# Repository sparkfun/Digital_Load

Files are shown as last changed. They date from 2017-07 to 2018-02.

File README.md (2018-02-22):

Digital_Load
==========================================

Variable Load

A PSoC-based digital load that allows the user to set a desired current which will be maintained despite changes in voltage supply.
Check on the [SparkFun Enginursday post](https://www.sparkfun.com/news/2434) about the project build or the [SparkFun Variable Load Kit](https://www.sparkfun.com/products/14449) that uses this design. 

License Information
-------------------

This product is _**open source**_! 

Please review the LICENSE.md file for license information. 

If you have any questions or concerns on licensing, please contact techsupport@sparkfun.com.

Distributed as-is; no warranty is given.

- Your friends at SparkFun.

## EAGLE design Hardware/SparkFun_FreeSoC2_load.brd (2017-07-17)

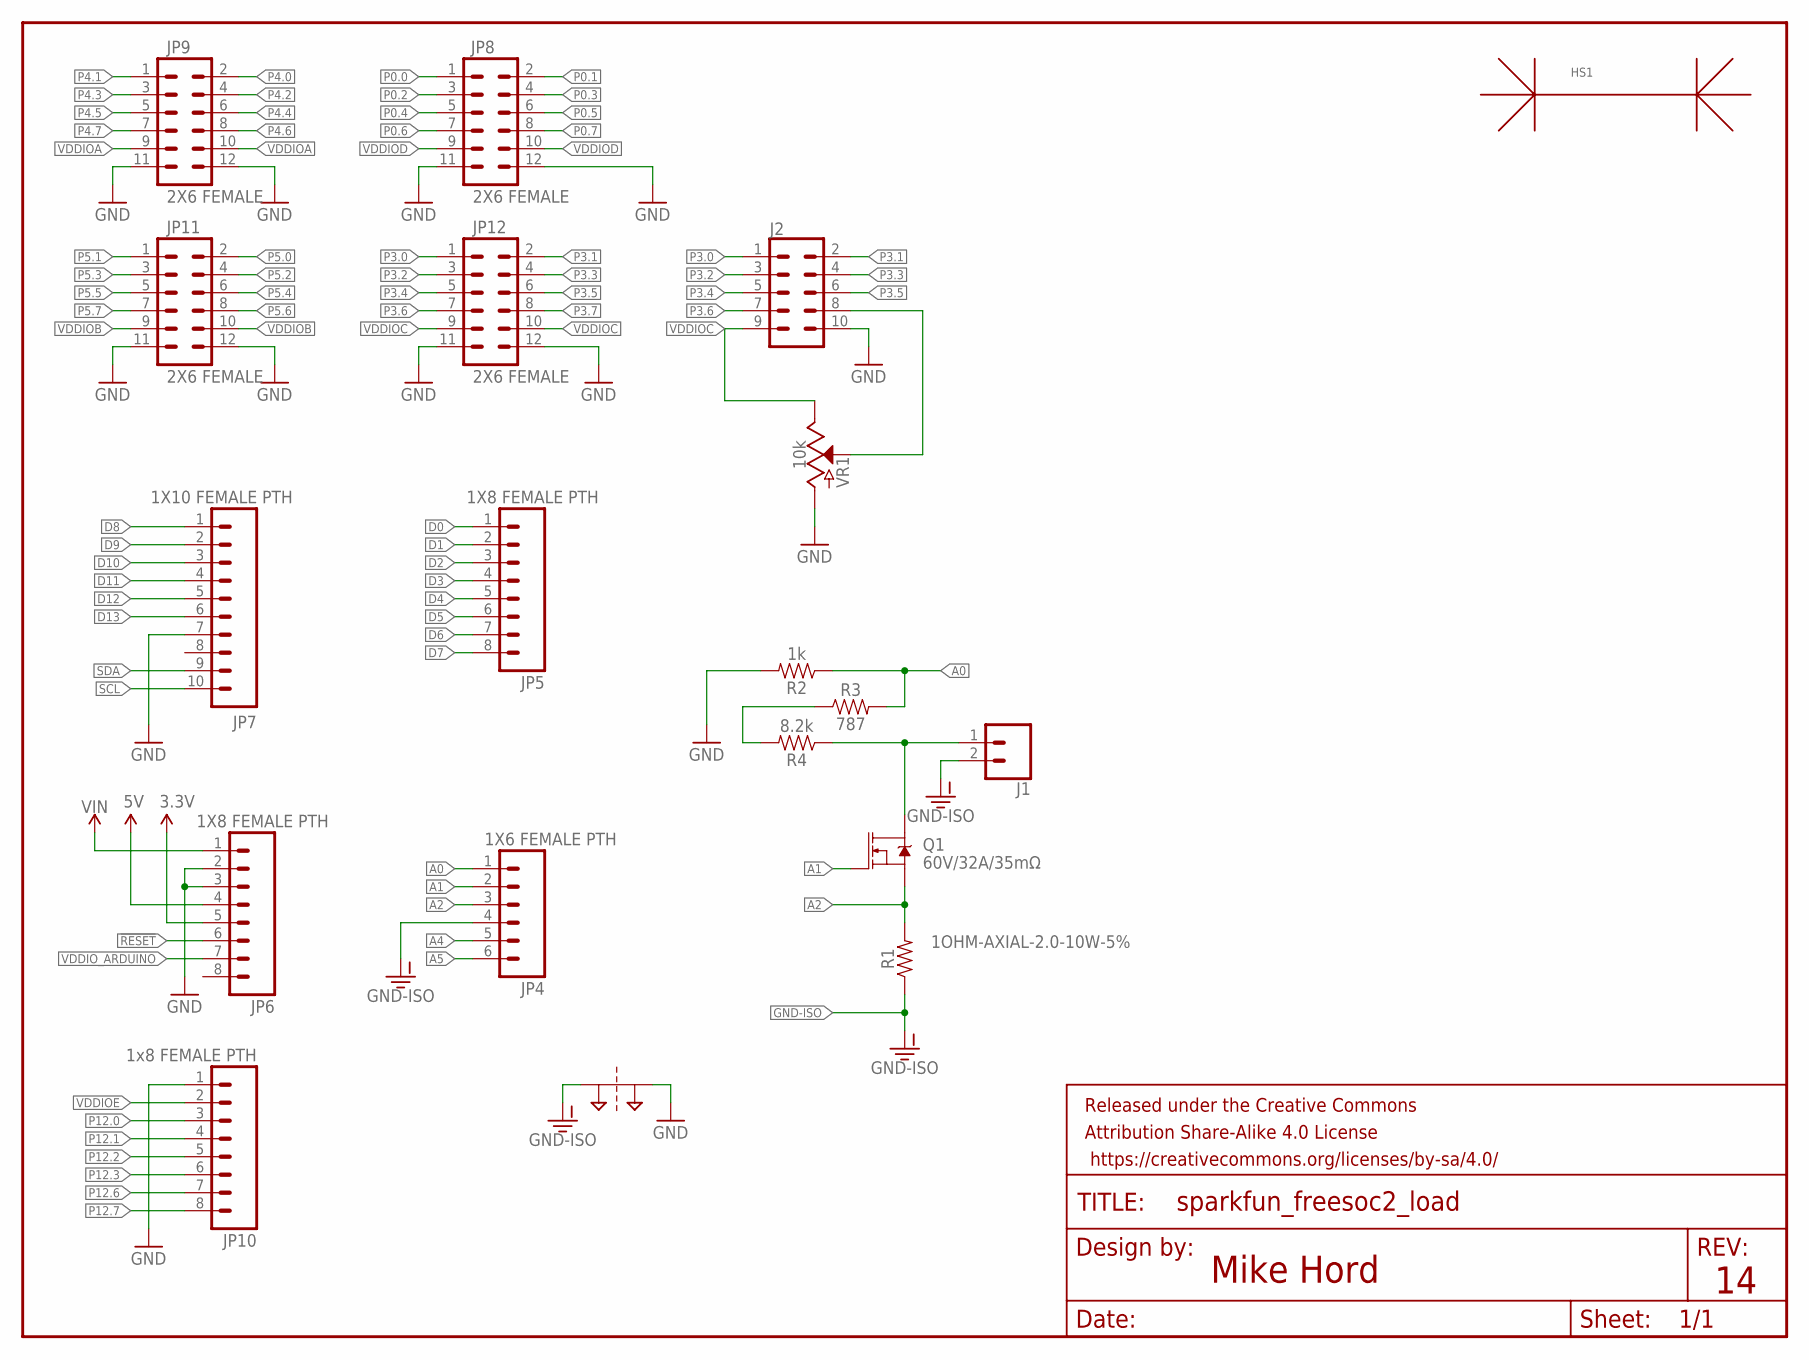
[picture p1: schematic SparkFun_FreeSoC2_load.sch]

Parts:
FRAME3: FRAME-LETTERNO_PACKAGE; DUMMY
HS1: HEATSINKPRT-9576; HEATSINK_PRT-9576
J1: CONN_023.5MM; SCREWTERMINAL-3.5MM-2
J2: CONN_05X2SHD; 2X5-SHROUDED
JP4: 1X6 FEMALE PTH; 1X06-SIP_LOCK
JP5, JP6: 1X8 FEMALE PTH; 1X08_LOCK
JP7: 1X10 FEMALE PTH; 1X10_LOCK
JP8, JP9, JP11, JP12: 2X6 FEMALE; 2X6
JP10: 1x8 FEMALE PTH; 1X08_LOCK
Q1: 60V/32A/35mΩ; TO220V
R1: 1OHM-AXIAL-2.0-10W-5%; AXIAL-2.0
R2: 1k; 0603
R3: 787; 0603
R4: 8.2k; 0603
SUPPLY2: 2PT_GND_TIE
VR1: 10k; POT-PTH-ALPS

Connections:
3.3V: JP6.5
5V: JP6.4
!RESET: JP6.6
A0: JP4.1, R2.1, R3.2
A1: JP4.2, Q1.1 (G)
A2: JP4.3, Q1.3 (S), R1.P$2 (2)
A4: JP4.5
A5: JP4.6
D0: JP5.1
D1: JP5.2
D2: JP5.3
D3: JP5.4
D4: JP5.5
D5: JP5.6
D6: JP5.7
D7: JP5.8
D8: JP7.1
D9: JP7.2
D10: JP7.3
D11: JP7.4
D12: JP7.5
D13: JP7.6
GND: J2.10, JP6.2, JP6.3, JP7.7, JP8.11, JP8.12, JP9.11, JP9.12, JP10.1, JP11.11, JP11.12, JP12.11, JP12.12, R2.2, SUPPLY2.P$1, VR1.P$3 (A)
GND-ISO: J1.2, JP4.4, R1.P$1 (1), SUPPLY2.P$2
unnamed: J1.1, Q1.2 (D), R4.1
unnamed: R3.1, R4.2
unnamed: J2.8, VR1.P$2 (S)
P0.0: JP8.1
P0.1: JP8.2
P0.2: JP8.3
P0.3: JP8.4
P0.4: JP8.5
P0.5: JP8.6
P0.6: JP8.7
P0.7: JP8.8
P3.0: J2.1, JP12.1
P3.1: J2.2, JP12.2
P3.2: J2.3, JP12.3
P3.3: J2.4, JP12.4
P3.4: J2.5, JP12.5
P3.5: J2.6, JP12.6
P3.6: J2.7, JP12.7
P3.7: JP12.8
P4.0: JP9.2
P4.1: JP9.1
P4.2: JP9.4
P4.3: JP9.3
P4.4: JP9.6
P4.5: JP9.5
P4.6: JP9.8
P4.7: JP9.7
P5.0: JP11.2
P5.1: JP11.1
P5.2: JP11.4
P5.3: JP11.3
P5.4: JP11.6
P5.5: JP11.5
P5.6: JP11.8
P5.7: JP11.7
P12.0: JP10.3
P12.1: JP10.4
P12.2: JP10.5
P12.3: JP10.6
P12.6: JP10.7
P12.7: JP10.8
SCL: JP7.10
SDA: JP7.9
VDDIOA: JP9.9, JP9.10
VDDIOB: JP11.9, JP11.10
VDDIOC: J2.9, JP12.9, JP12.10, VR1.P$1 (E)
VDDIOD: JP8.9, JP8.10
VDDIOE: JP10.2
VDDIO_ARDUINO: JP6.7
VIN: JP6.1

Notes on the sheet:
Mike Hord

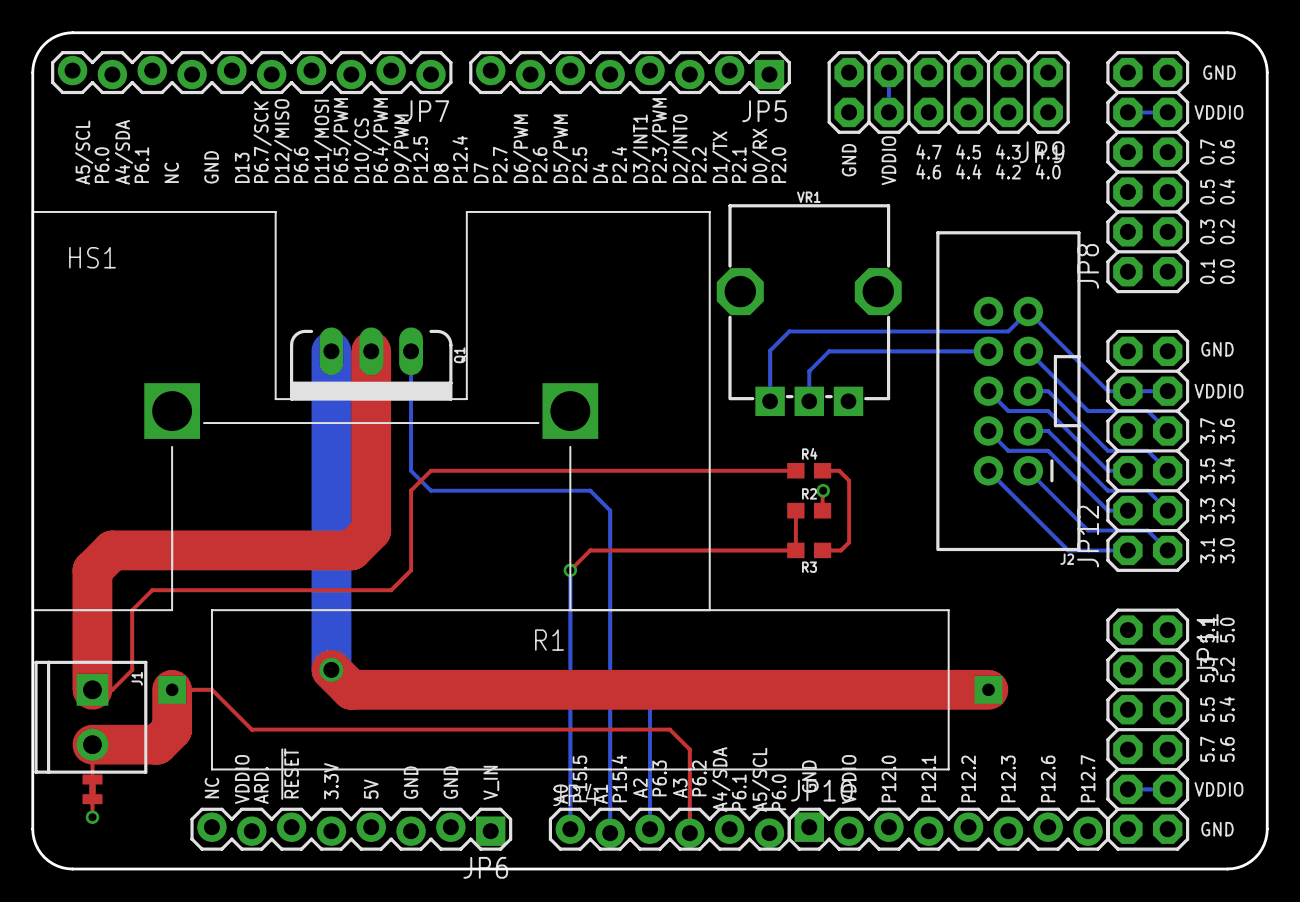
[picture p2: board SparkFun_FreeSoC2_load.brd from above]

Board: 4 copper layers, 78.7 x 53.3 mm, 21 parts (0 on the bottom side), 19 nets.

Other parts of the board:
U$2: CREATIVE_COMMONS@1

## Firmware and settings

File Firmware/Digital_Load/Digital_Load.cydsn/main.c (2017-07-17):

/* ========================================
 *
 * Copyright YOUR COMPANY, THE YEAR
 * All Rights Reserved
 * UNPUBLISHED, LICENSED SOFTWARE.
 *
 * CONFIDENTIAL AND PROPRIETARY INFORMATION
 * WHICH IS THE PROPERTY OF your company.
 *
 * ========================================
*/
#include "project.h"
#include <stdbool.h>
#include <stdio.h>
#include <stdlib.h>
#include "MPR121.h"
#include "digital_load.h"

#define KP  0.15
#define KI  0.10
#define KD  0

// systemTimer is incremented in the tickISR, which occurs once a millisecond.
//  It's the timebase for the entire firmware, upon which all other timing
//  is based.
volatile int32 systemTimer = 0;
CY_ISR_PROTO(tickISR);

CY_ISR_PROTO(keypadISR);
volatile bool keyPressOccurred = false; 

int main(void)
{
  CyGlobalIntEnable; /* Enable global interrupts. */
  
  // ARM devices have an internal system tick which can be used as a timebase
  // without having to tie up additional system resources. Here we set it up to
  // point to our system tick ISR and configure it to occur once every 64000
  // clock ticks, which is once per millisecond on our 64MHz processor.
  CyIntSetSysVector((SysTick_IRQn + 16), tickISR);
  SysTick_Config(64000);
  
  // Create our timing "tick" variables. These are used to record when the last
  // iteration of an action in the main loop happened and to trigger the next
  // iteration when some number of clock ticks have passed.
  int32_t _20HzTick = 0;
  int32_t _1kHzTick = 0;
  
  Gate_Drive_Tune_Start();
  Offset_Start();
  Offset_Gain_Start();
  GDT_Buffer_Start();
  O_Buffer_Start();
  LCD_Start();
  LCD_DisplayOn();
  I2C_Start();
  Keypad_Interrupt_StartEx(keypadISR);
  Source_ADC_Start();
  I_Source_ADC_Start();
  CyDelay(100);
  mpr121QuickConfig();
  LCD_PrintString("Hello, world");
  
  uint8_t mode = DISPLAY;
  float iLimit = 1;
  float error = 0.0;
  float lastError = 0.0;
  float integral = 0.0;
  float derivative = 0.0;
  float vSource = 0.0;
  int16_t vSourceRaw = 0;
  float iSource = 0.0;
  float setPoint = 0.0;
  int32_t iSourceRaw = 0;
  int8_t keypadValue = -1;
  uint16_t grossSetPoint = 64;
  uint16_t fineSetPoint = 0;
  
  Offset_SetValue(grossSetPoint);
  Gate_Drive_Tune_SetValue(fineSetPoint);
  
  for(;;)
  {
    char buff[16];
    
    if (systemTimer - 1 > _1kHzTick)
    {
      _1kHzTick = systemTimer;
      I_Source_ADC_StartConvert();
      I_Source_ADC_IsEndConversion(I_Source_ADC_WAIT_FOR_RESULT);
      iSourceRaw = I_Source_ADC_GetResult32();
      iSource = 10 * I_Source_ADC_CountsTo_Volts(iSourceRaw);
      lastError = error;
      error = iLimit - iSource;
      integral = integral + error;
      derivative = error - lastError;
      setPoint = (KP * error) + (KI * integral) + (KD * derivative);
      
      // setPoint is a floating point voltage. We need to convert that
      //  into an integer that can be fed into our DACs.
      // First, find our grossSetPoint. This is a largish voltage that
      //  represents a coarse 0-4V offset in 16mV steps.
      grossSetPoint = (int)(setPoint / 0.016);
      // We want to limit our gross offset to 255, since it's an 8-bit
      //  DAC output.
      if (grossSetPoint > 255) grossSetPoint = 255;
      // Now, find the fineSetPoint. This is a 4mV step 8-bit DAC which
      //  allows us to tune the set point a little more finely.
      fineSetPoint = (int)((setPoint - grossSetPoint*0.016)/0.004);
      // Finally, one last check: if the source voltage is below 0.3V,
      //  we want to make both of our output values ZERO.
      Source_ADC_StartConvert();
      Source_ADC_IsEndConversion(Source_ADC_WAIT_FOR_RESULT);
      vSourceRaw = Source_ADC_GetResult16();
      vSource = 10*Source_ADC_CountsTo_Volts(vSourceRaw);
      if (vSource < 0.3)
      {
        error = 0;
        lastError = 0;
        integral = 0;
        derivative = 0;
        grossSetPoint = 0;
        fineSetPoint = 0;
      }
      Offset_SetValue(grossSetPoint);
      Gate_Drive_Tune_SetValue(fineSetPoint);
    } // if (systemTimer - 50 > _20HzTick)
    if (systemTimer - 200 > _20HzTick)
    {
      _20HzTick = systemTimer;
      Source_ADC_StartConvert();
      Source_ADC_IsEndConversion(Source_ADC_WAIT_FOR_RESULT);
      vSourceRaw = Source_ADC_GetResult16();
      vSource = 10*Source_ADC_CountsTo_Volts(vSourceRaw);
      
      if (keyPressOccurred == true)
      {
        keyPressOccurred = false;
        keypadValue = getKeypadNumber();
      } // if (keyPressOccurred == true)
      if (mode == DISPLAY)
      {
        LCD_ClearDisplay();
        LCD_PrintString("Press 1 to set I");
        LCD_Position(1,0);
        sprintf(buff, "I Lim: %.3f", iLimit);
        LCD_PrintString(buff);
        LCD_Position(2,0);
        sprintf(buff, "V Source: %.3f", vSource);
        LCD_PrintString(buff);
        LCD_Position(3,0);
        sprintf(buff, "I Source: %.3f", iSource);
        LCD_PrintString(buff);
        if (keypadValue == 1) 
        {
          mode = SET;
          sprintf(buff, "0");
          keypadValue = -1;
        }
      } // if (mode == DISPLAY)
      if (mode == SET)
      {
        LCD_ClearDisplay();
        LCD_PrintString("Set current in A");
        LCD_Position(1,0);
        LCD_PrintString(buff);
        if (keypadValue == ENTER)
        {
          mode = DISPLAY;
          float temp = atoff(buff);
          if (temp) iLimit = temp;
        }
        if (keypadValue != -1)
        {
          if (keypadValue == 0) strcat(buff, "0");
          else if (keypadValue == 1) strcat(buff, "1");
          else if (keypadValue == 2) strcat(buff, "2");
          else if (keypadValue == 3) strcat(buff, "3");
          else if (keypadValue == 4) strcat(buff, "4");
          else if (keypadValue == 5) strcat(buff, "5");
          else if (keypadValue == 6) strcat(buff, "6");
          else if (keypadValue == 7) strcat(buff, "7");
          else if (keypadValue == 8) strcat(buff, "8");
          else if (keypadValue == 9) strcat(buff, "9");
          else if (keypadValue == 10) strcat(buff, ".");
          keypadValue = -1;
        }
      } // if (mode == SET)
    } // if (systemTimer - 200 > _5HzTick)
    
  }
  return 0;
}

CY_ISR(keypadISR)
{
  keyPressOccurred = true;
  Keypad_Interrupt_ClearPending();
  keypadIRQ_ClearInterrupt();
}

CY_ISR(tickISR)
{
  systemTimer++;
}

/* [] END OF FILE */

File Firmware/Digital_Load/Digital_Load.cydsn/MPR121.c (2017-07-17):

#include <project.h>
#include "MPR121.h"

void mpr121Write(unsigned char address, unsigned char data)
{
  I2C_MasterSendStart(0x5a, 0);
  I2C_MasterWriteByte(address);
  I2C_MasterWriteByte(data);
  I2C_MasterSendStop();
}

uint8_t mpr121Read(uint8_t address)
{
  uint8_t data;
  I2C_MasterSendStart(0x5a, 0);
  I2C_MasterWriteByte(address);
  I2C_MasterSendRestart(0x5a,1);
  data = I2C_MasterReadByte(I2C_NAK_DATA);
  I2C_MasterSendStop();
  return data;
}

void mpr121QuickConfig(void)
{
  // Section A
  // This group controls filtering when data is > baseline.
  mpr121Write(MHD_R, 0x01);
  mpr121Write(NHD_R, 0x01);
  mpr121Write(NCL_R, 0x00);
  mpr121Write(FDL_R, 0x00);

  // Section B
  // This group controls filtering when data is < baseline.
  mpr121Write(MHD_F, 0x01);
  mpr121Write(NHD_F, 0x01);
  mpr121Write(NCL_F, 0xFF);
  mpr121Write(FDL_F, 0x02);
  
  // Section C
  // This group sets touch and release thresholds for each electrode
  mpr121Write(ELE0_T, TOU_THRESH);
  mpr121Write(ELE0_R, REL_THRESH);
  mpr121Write(ELE1_T, TOU_THRESH);
  mpr121Write(ELE1_R, REL_THRESH);
  mpr121Write(ELE2_T, TOU_THRESH);
  mpr121Write(ELE2_R, REL_THRESH);
  mpr121Write(ELE3_T, TOU_THRESH);
  mpr121Write(ELE3_R, REL_THRESH);
  mpr121Write(ELE4_T, TOU_THRESH);
  mpr121Write(ELE4_R, REL_THRESH);
  mpr121Write(ELE5_T, TOU_THRESH);
  mpr121Write(ELE5_R, REL_THRESH);
  mpr121Write(ELE6_T, TOU_THRESH);
  mpr121Write(ELE6_R, REL_THRESH);
  mpr121Write(ELE7_T, TOU_THRESH);
  mpr121Write(ELE7_R, REL_THRESH);
  mpr121Write(ELE8_T, TOU_THRESH);
  mpr121Write(ELE8_R, REL_THRESH);
  mpr121Write(ELE9_T, TOU_THRESH);
  mpr121Write(ELE9_R, REL_THRESH);
  mpr121Write(ELE10_T, TOU_THRESH);
  mpr121Write(ELE10_R, REL_THRESH);
  mpr121Write(ELE11_T, TOU_THRESH);
  mpr121Write(ELE11_R, REL_THRESH);
  
  // Section D
  // Set the Filter Configuration
  // Set ESI2
  mpr121Write(FIL_CFG, 0x04);
  
  // Section E
  // Electrode Configuration
  // Enable 6 Electrodes and set to run mode
  // Set ELE_CFG to 0x00 to return to standby mode
  mpr121Write(ELE_CFG, 0x0C);	// Enables all 12 Electrodes
  //mpr121Write(ELE_CFG, 0x06);		// Enable first 6 electrodes
  
  // Section F
  // Enable Auto Config and auto Reconfig
  /*mpr121Write(ATO_CFG0, 0x0B);
  mpr121Write(ATO_CFGU, 0xC9);	// USL = (Vdd-0.7)/vdd*256 = 0xC9 @3.3V   
  mpr121Write(ATO_CFGL, 0x82);	// LSL = 0.65*USL = 0x82 @3.3V
  mpr121Write(ATO_CFGT, 0xB5);*/	// Target = 0.9*USL = 0xB5 @3.3V
}

int8_t getKeypadNumber(void)
{
  uint16_t touchStatus;
  uint8_t touchNumber=0;
  uint8_t j = 0;
  touchStatus = mpr121Read(0x01) << 8;
  touchStatus |= mpr121Read(0x00);
  for (j=0; j<12; j++)  // Check how many electrodes were pressed
  {
    if ((touchStatus & (1<<j)))
      touchNumber++;
  }
  if (touchNumber > 1) return -1;
  if (touchStatus & 1<<0) return 9;
  else if (touchStatus & 1<<1) return 6;
  else if (touchStatus & 1<<2) return 3;
  else if (touchStatus & 1<<3) return ENTER;
  else if (touchStatus & 1<<4) return 8;
  else if (touchStatus & 1<<5) return 5;
  else if (touchStatus & 1<<6) return 2;
  else if (touchStatus & 1<<7) return DECIMAL;
  else if (touchStatus & 1<<8) return 7;
  else if (touchStatus & 1<<9) return 4;
  else if (touchStatus & 1<<10) return 1;
  else if (touchStatus & 1<<11) return 0;
  else return -1;
}

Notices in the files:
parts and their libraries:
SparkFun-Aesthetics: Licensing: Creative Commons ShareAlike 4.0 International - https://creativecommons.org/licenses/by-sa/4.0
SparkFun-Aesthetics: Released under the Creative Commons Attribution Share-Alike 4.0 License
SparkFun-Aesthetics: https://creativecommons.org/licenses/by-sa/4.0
